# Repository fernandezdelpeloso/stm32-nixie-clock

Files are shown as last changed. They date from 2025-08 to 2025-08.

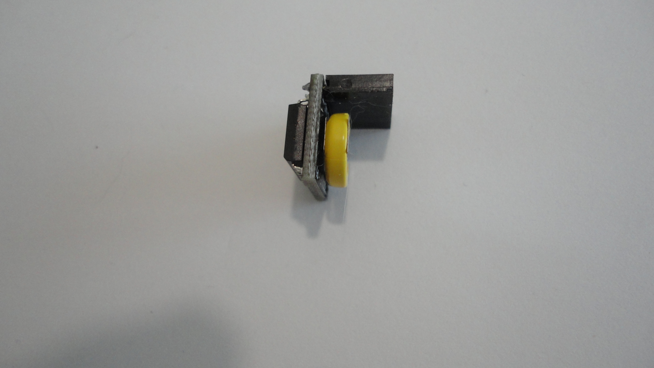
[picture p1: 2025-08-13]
media/images/DSC00116.JPG

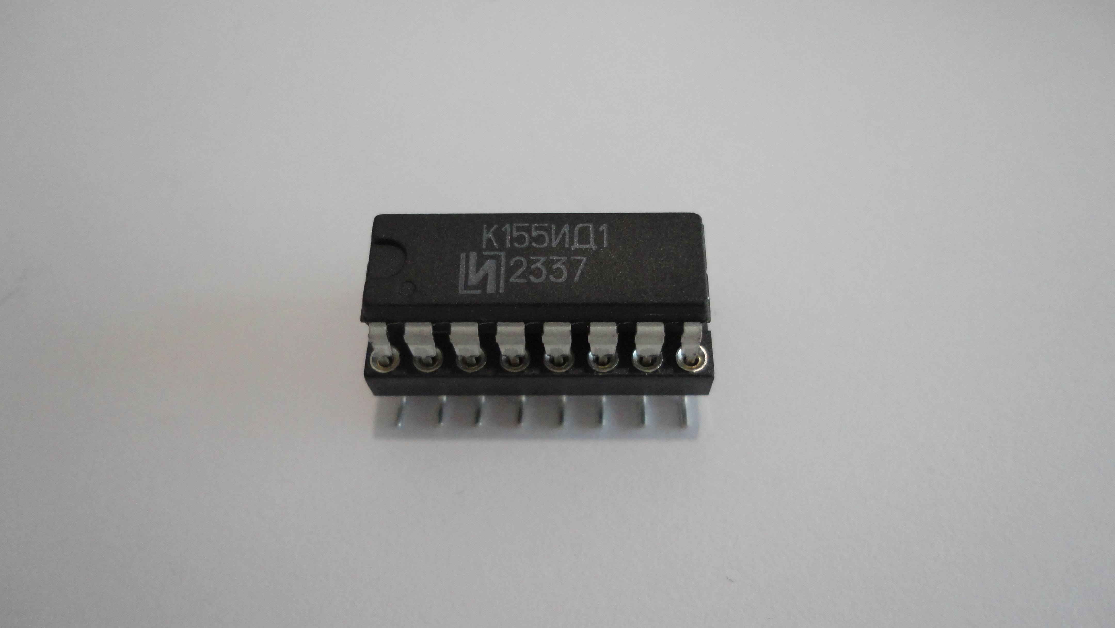
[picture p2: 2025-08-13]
media/images/DSC00112.JPG

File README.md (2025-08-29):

# STM32 Nixie Clock (R|Z568M)

**TL;DR:** One-tube Nixie clock (Dalibor Farny R|Z568M) on an STM32 Cortex-M4F with GPS time sync, RTC backup, and anti–cathode-poisoning routine.

[▶ Short demo (MP4)](media/videos/bright.mp4)
Thumbnail

## Hardware
- MCU: STM32L4A6RGT7
- Level shifting: PCA9306 (custom module)
- HV driver: K155ID1 (5 V logic)
- Time: NEO-M8N (UTC) + DS3231 (backup)

### Files in this repo
- Schematics (PDF): `hardware/exports/schematic/`
- PCB (design): `hardware/exporta/pcb`
- 3D (PCB model): `hardware/exports/3d/`
- BOM (CSV + iBOM): `hardware/exports/bom/`
- Native KiCad project: `hardware/kicad/`

## Firmware
`firmware/` (STM32CubeIDE project). Roadmap: GPS/NMEA parse, RTC sync, presence sensor → anti-poisoning routine, optional FreeRTOS + SystemView.

## Safety
**High voltage present.** Observe clearance/creepage and safe handling.

## License
MIT

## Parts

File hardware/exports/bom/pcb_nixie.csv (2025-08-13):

Reference | Value | Datasheet | Footprint | Qty | DNP
D1 | US1M_R3G | https://www.diodes.com/assets/Datasheets/ds16008.pdf | Diode_SMD:D_SMA | 1
D2 | SMAJ170A | https://www.littelfuse.com/media?itemid=75e32973-b177-4ee3-a0ff-cedaf1abdb93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 | Diode_SMD:D_SMA | 1
J1 | MCU SWD | B4B-XH-AMLFSN | Connector_JST:JST_XH_B4B-XH-A_1x04_P2.50mm_Vertical | 1
J2 | Omron | B4B-XH-AMLFSN | Connector_JST:JST_XH_B4B-XH-A_1x04_P2.50mm_Vertical | 1
J3 | GPS M8N | B4B-XH-AMLFSN | Connector_JST:JST_XH_B4B-XH-A_1x04_P2.50mm_Vertical | 1
J4 | Power_supply |  | Connector_JST:JST_XH_B4B-XH-A_1x04_P2.50mm_Vertical | 1
J5 | Littelfuse 0218.020HXP | B2B-XH-ALFSN | Connector_JST:JST_XH_B2B-XH-A_1x02_P2.50mm_Vertical | 1
J6 | OLED | B4B-XH-AMLFSN | Connector_JST:JST_XH_B4B-XH-A_1x04_P2.50mm_Vertical | 1
NX1 | FRONT |  | Nixie:nixie_socket_manual | 1
R0 | 1k2 | ~ | Resistor_SMD:R_1206_3216Metric | 1
R1,R10 | 4k7 | ~ | Resistor_SMD:R_1206_3216Metric,Resistor_SMD:R_2512_6332Metric | 2
R2,R5,R6 | 1k1 | ~ | Resistor_SMD:R_1206_3216Metric | 3
R3 | 1k5 | ~ | Resistor_SMD:R_1206_3216Metric | 1
R4 | 3k3 | ~ | Resistor_SMD:R_1206_3216Metric | 1
R7 | 3k6 | ~ | Resistor_SMD:R_1206_3216Metric | 1
R8 | 0R | ~ | Resistor_SMD:R_1206_3216Metric | 1
R9 | 1k | ~ | Resistor_SMD:R_1206_3216Metric | 1
RC0,RC1,RD0,RD1 | 10k | ~ | Resistor_SMD:R_0603_1608Metric | 4
REN1 | 200k | ~ | Resistor_SMD:R_0603_1608Metric | 1
U1 | STM32L4A6RGTx | https://www.st.com/resource/en/datasheet/stm32l4a6rg.pdf | Package_QFP:LQFP-64_10x10mm_P0.5mm | 1
U1C1 | 4.7U | ~ | Capacitor_SMD:C_0603_1608Metric | 1
U1C2,U1C3,U1C4,U1C5,U2C1,U2C2 | 100N | ~ | Capacitor_SMD:C_0603_1608Metric,Capacitor_SMD:C_0805_2012Metric | 6
U1C6 | 10N | ~ | Capacitor_SMD:C_0603_1608Metric | 1
U1C7,U3C1 | 1U | ~ | Capacitor_SMD:C_0603_1608Metric,Capacitor_SMD:C_0805_2012Metric | 2
U2 | TXB0104PW | http://www.ti.com/lit/ds/symlink/txb0104.pdf | Package_SO:TSSOP-14_4.4x5mm_P0.65mm | 1
U3 | K155id1 | datasheets/k155na1.pdf | Package_DIP:SMDIP-16_W7.62mm | 1
U4 | PCA9306D | https://www.nxp.com/docs/en/data-sheet/PCA9306.pdf | Package_SO:SO-8_3.9x4.9mm_P1.27mm | 1
U4C1 | 100P | ~ | Capacitor_SMD:C_0201_0603Metric | 1

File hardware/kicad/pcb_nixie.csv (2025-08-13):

Source: | /home/eduardo/Documents/070_NIXIE_CLOCK/pcb_nixie/pcb_nixie.kicad_sch
Date: | Do 29 Aug 2024 03:46:50 CEST
Tool: | Eeschema 6.0.2+dfsg-1
Generator: | /usr/share/kicad/plugins/bom_csv_grouped_by_value.py
Component Count: | 23
Individual Components:
Item | Qty | Reference(s) | Value | LibPart | Footprint | Datasheet | Spice_Model | Spice_Netlist_Enabled | Spice_Primitive
 |  | J1 | Conn_01x04_MountingPin | Connector_Generic_MountingPin:Conn_01x04_MountingPin | Connector_Molex:Molex_KK-254_AE-6410-04A_1x04_P2.54mm_Vertical | ~
 |  | NX1 | RTS-5 | NIXIEBIG:RTS-5 | Nixie:nixie_socket_manual
 |  | R0 | 1k2 | Device:R | Resistor_SMD:R_1206_3216Metric | ~
 |  | R1 | 4k7 | Device:R | Resistor_SMD:R_1206_3216Metric | ~
 |  | R2 | 1k1 | Device:R | Resistor_SMD:R_1206_3216Metric | ~
 |  | R3 | 1k5 | Device:R | Resistor_SMD:R_1206_3216Metric | ~
 |  | R4 | 3k3 | Device:R | Resistor_SMD:R_1206_3216Metric | ~
 |  | R5 | 1k1 | Device:R | Resistor_SMD:R_1206_3216Metric | ~
 |  | R6 | 1k1 | Device:R | Resistor_SMD:R_1206_3216Metric | ~
 |  | R7 | 3k6 | Device:R | Resistor_SMD:R_1206_3216Metric | ~
 |  | R8 | 0R | Device:R | Resistor_SMD:R_1206_3216Metric | ~
 |  | R9 | 1k | Device:R | Resistor_SMD:R_1206_3216Metric | ~ | 1k | Y | R
 |  | R11 | 4k7 | Device:R | Resistor_SMD:R_2512_6332Metric | ~
 |  | U1 | STM32F103RCT6 | MCU_ST_STM32F1:STM32F103RCTx | Package_QFP:LQFP-64_10x10mm_P0.5mm | http://www.st.com/st-web-ui/static/active/en/resource/technical/document/datasheet/CD00191185.pdf
 |  | U1C1 | 1U | Device:C | Capacitor_SMD:C_0805_2012Metric | ~
 |  | U1C2 | 1U | Device:C | Capacitor_SMD:C_0805_2012Metric | ~
 |  | U2 | TXB0104D | Logic_LevelTranslator:TXB0104D | Package_SO:SOIC-14_3.9x8.7mm_P1.27mm | http://www.ti.com/lit/ds/symlink/txb0104.pdf
 |  | U2C1 | 1U | Device:C | Capacitor_SMD:C_0805_2012Metric | ~
 |  | U2C2 | 1U | Device:C | Capacitor_SMD:C_0805_2012Metric | ~
 |  | U2C3 | 1U | Device:C | Capacitor_SMD:C_0805_2012Metric | ~
 |  | U3 | 155ИД1 | misc_giogziro95:155ИД1 | Package_DIP:SMDIP-16_W7.62mm | https://neon1.net/nixieclock/sn74141.pdf
 |  | U3C1 | 1U | Device:C | Capacitor_SMD:C_0805_2012Metric | ~
 |  | U3C2 | 1U | Device:C | Capacitor_SMD:C_0805_2012Metric | ~
Collated Components:
Item | Qty | Reference(s) | Value | LibPart | Footprint | Datasheet | Spice_Model | Spice_Netlist_Enabled | Spice_Primitive
1 | 1 | J1 | Conn_01x04_MountingPin | Connector_Generic_MountingPin:Conn_01x04_MountingPin | Connector_Molex:Molex_KK-254_AE-6410-04A_1x04_P2.54mm_Vertical | ~
2 | 1 | NX1 | RTS-5 | NIXIEBIG:RTS-5 | Nixie:nixie_socket_manual
3 | 1 | R0 | 1k2 | Device:R | Resistor_SMD:R_1206_3216Metric | ~
4 | 1 | R1 | 4k7 | Device:R | Resistor_SMD:R_1206_3216Metric | ~
5 | 3 | R2, R5, R6 | 1k1 | Device:R | Resistor_SMD:R_1206_3216Metric | ~
6 | 1 | R3 | 1k5 | Device:R | Resistor_SMD:R_1206_3216Metric | ~
7 | 1 | R4 | 3k3 | Device:R | Resistor_SMD:R_1206_3216Metric | ~
8 | 1 | R7 | 3k6 | Device:R | Resistor_SMD:R_1206_3216Metric | ~
9 | 1 | R8 | 0R | Device:R | Resistor_SMD:R_1206_3216Metric | ~
10 | 1 | R9 | 1k | Device:R | Resistor_SMD:R_1206_3216Metric | ~ | 1k | Y | R
11 | 1 | R11 | 4k7 | Device:R | Resistor_SMD:R_2512_6332Metric | ~
12 | 1 | U1 | STM32F103RCT6 | MCU_ST_STM32F1:STM32F103RCTx | Package_QFP:LQFP-64_10x10mm_P0.5mm | http://www.st.com/st-web-ui/static/active/en/resource/technical/document/datasheet/CD00191185.pdf
13 | 7 | U1C1, U1C2, U2C1, U2C2, U2C3, U3C1, U3C2 | 1U | Device:C | Capacitor_SMD:C_0805_2012Metric | ~
14 | 1 | U2 | TXB0104D | Logic_LevelTranslator:TXB0104D | Package_SO:SOIC-14_3.9x8.7mm_P1.27mm | http://www.ti.com/lit/ds/symlink/txb0104.pdf
15 | 1 | U3 | 155ИД1 | misc_giogziro95:155ИД1 | Package_DIP:SMDIP-16_W7.62mm | https://neon1.net/nixieclock/sn74141.pdf

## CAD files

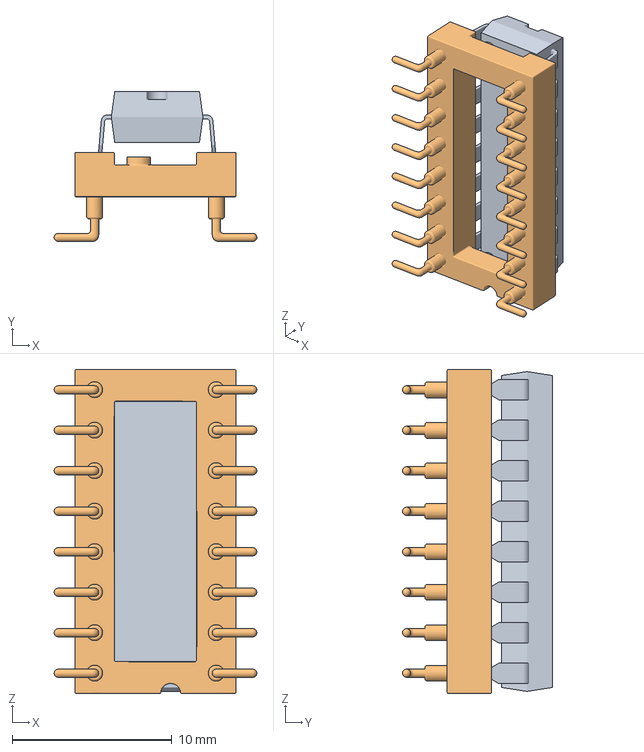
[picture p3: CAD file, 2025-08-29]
hardware/kicad/DIP16_TO_SMD.FCStd
12.7 x 9.40 x 20.3 mm
Scale001
dip_to_smd_socket110-xx-316-41-105000

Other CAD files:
hardware/kicad/1N5819HW_7_F/DIP-16 N.step
hardware/kicad/3d_models/B3B-XH-A.step
hardware/kicad/footprints/kicad-footprints-5.1.10/Sources/Inductor_SMD/L_Wuerth_WE-TPC-3816.FCStd
hardware/kicad/footprints/kicad-footprints-5.1.10/Sources/Package_LGA/Infineon_PG-LLGA-5-1.FCStd
hardware/kicad/footprints/kicad-footprints-5.1.10/Sources/Package_SON/X2SON-4_1x1mm_P0.65mm.fcstd
hardware/kicad/footprints/kicad-footprints-5.1.10/Sources/Package_TO_SOT_THT/sod-70.fcstd
hardware/kicad/16 DIP IC.stp
hardware/kicad/1N5819HW_7_F/1N5819HW-7-F.step
hardware/kicad/3d_models/B2B-XH-A.step
hardware/kicad/footprints/kicad-footprints-5.1.10/Sources/Inductor_SMD/L_Coilcraft_LPS5030.FCStd
hardware/kicad/footprints/kicad-footprints-5.1.10/Sources/Package_TO_SOT_THT/sod-70_P5.08mm.fcstd
hardware/kicad/DIP16withSOCKET.stl
hardware/kicad/DIP-16 N.step
hardware/kicad/Unnamed-Fusion.step
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

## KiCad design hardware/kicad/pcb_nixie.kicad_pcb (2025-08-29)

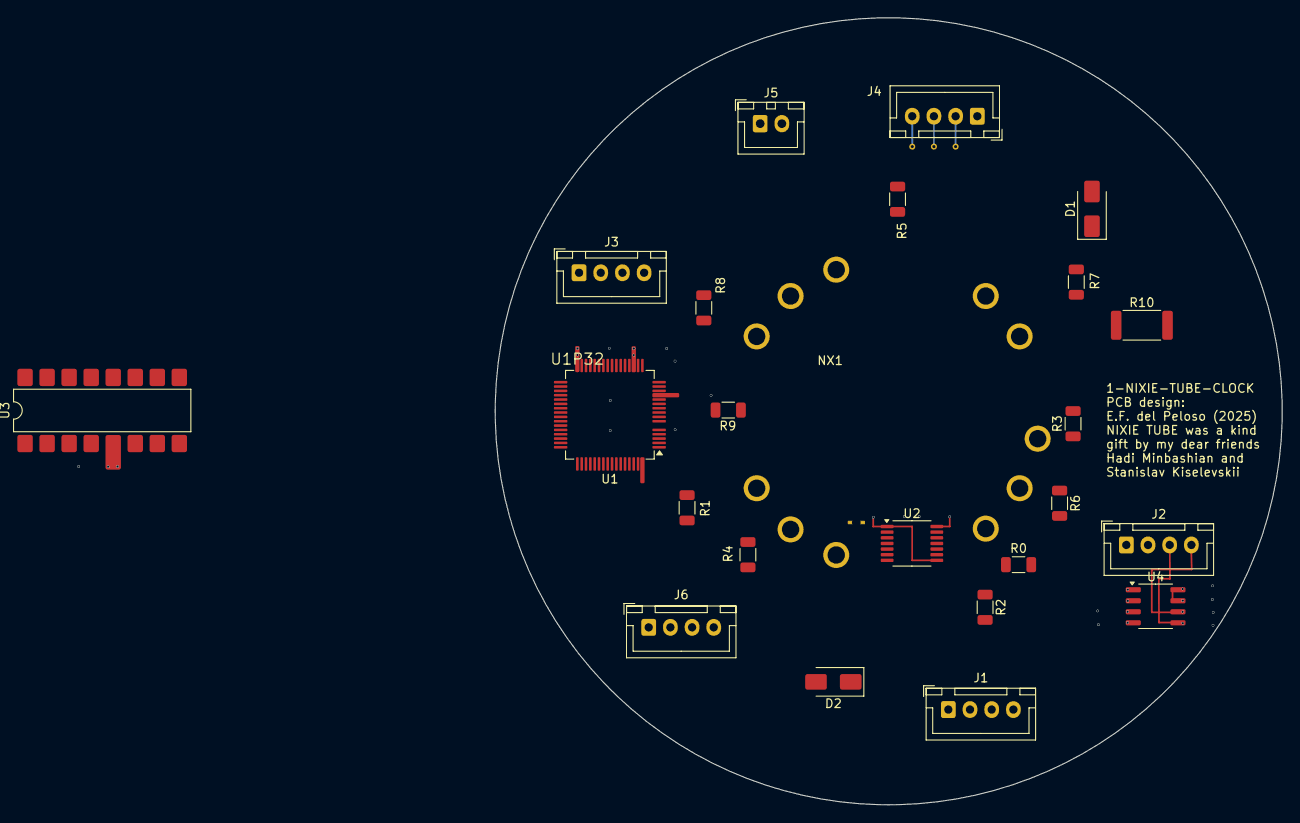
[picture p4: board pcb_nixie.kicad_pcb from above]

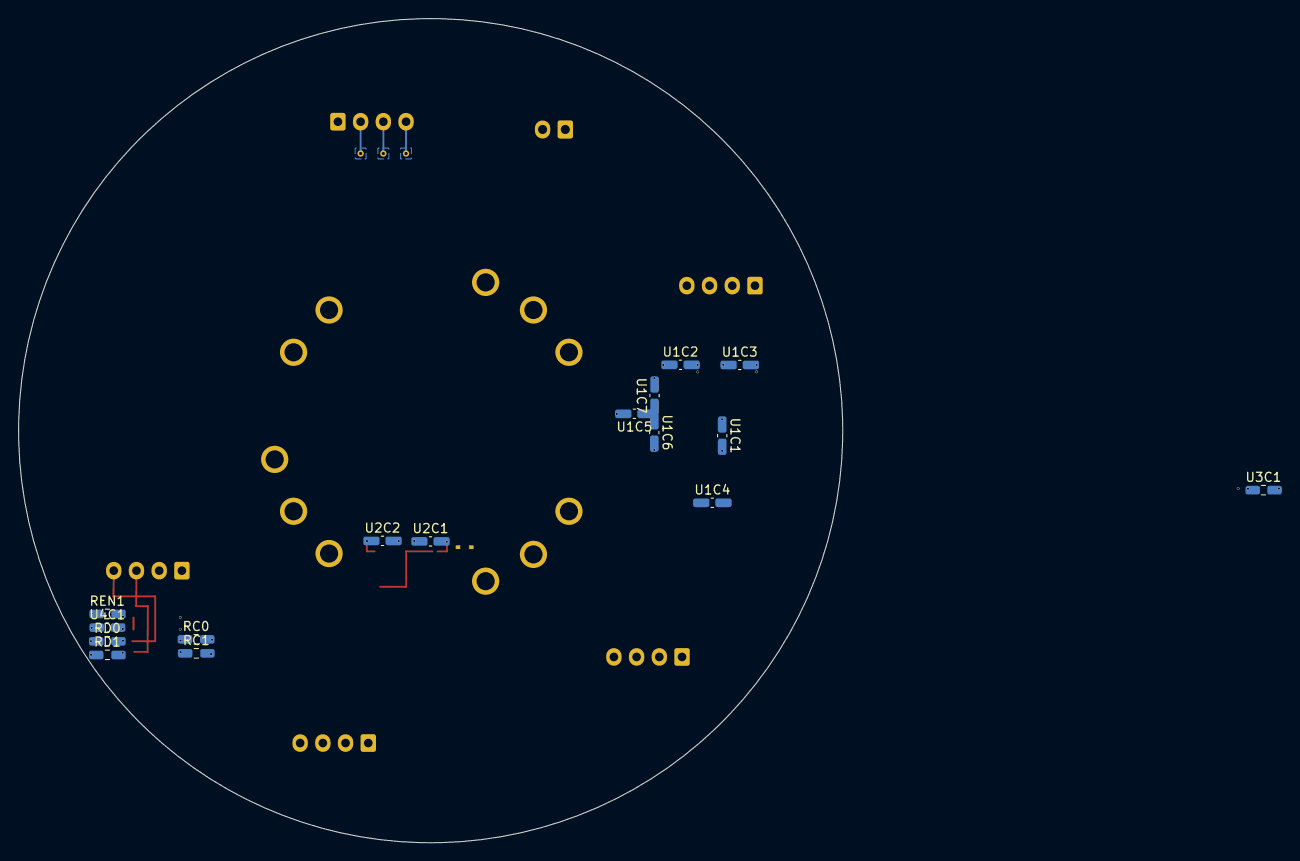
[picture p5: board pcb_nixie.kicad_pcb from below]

Board: 6 copper layers, 90.7 x 90.7 mm, 44 parts (16 on the bottom side), 45 nets, no tracks yet.

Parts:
D1: US1M_R3G; D_SMA
D2: SMAJ170A; D_SMA
J1: MCU-SWD; JST_XH_B4B-XH-A_1x04_P2.50mm_Vertical
J2: Omron; JST_XH_B4B-XH-A_1x04_P2.50mm_Vertical
J3: GPS-M8N; JST_XH_B4B-XH-A_1x04_P2.50mm_Vertical
J4: Power-supply; JST_XH_B4B-XH-A_1x04_P2.50mm_Vertical
J4P2, J4P3, J4P4: (no value)
J5: Littelfuse-0218.020HXP; JST_XH_B2B-XH-A_1x02_P2.50mm_Vertical
J6: OLED; JST_XH_B4B-XH-A_1x04_P2.50mm_Vertical
NX1: FRONT; nixie_socket_manual
R0: 1k2; R_1206_3216Metric
R1: 4k7; R_1206_3216Metric
R2, R5, R6: 1k1; R_1206_3216Metric
R3: 1k5; R_1206_3216Metric
R4: 3k3; R_1206_3216Metric
R7: 3k6; R_1206_3216Metric
R8: 0R; R_1206_3216Metric
R9: 1k; R_1206_3216Metric
R10: 4k7; R_2512_6332Metric
RC0, RC1: 10k; R_0603_1608Metric
RD0, RD1: 10k; R_0603_1608Metric
REN1: 200k; R_0603_1608Metric
U1: STM32L4A6RGTx; LQFP-64_10x10mm_P0.5mm
U1C1: 4.7U; C_0603_1608Metric
U1C2, U1C3, U1C4, U1C5, U1C6, U1C7, U2C1, U2C2: 100N; C_0603_1608Metric
U1P32: (no value)
U2: TXB0104PW; TSSOP-14_4.4x5mm_P0.65mm
U3: K155id1; SMDIP-16_W7.62mm
U3C1: 1U; R_0603_1608Metric
U4: PCA9306D; SO-8_3.9x4.9mm_P1.27mm
U4C1: 100P; C_0603_1608Metric

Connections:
+3V3: J3.4 (+3V3), J4.4 (3V3), J4P4.17, J6.3 (3V3), RC0.2, RC1.1, U1.1 (VBAT), U1.13 (VDDA), U1.19 (VDD), U1.32 (VDD), U1.48 (VDDUSB), U1C1.2, U1C2.2, U1P32.32 (VDD), U2.1 (VCCA), U2.8 (OE), U4.2 (VREF1)
+5V: J2.2 (+5V), J4.3 (5V), J4P3.16, RD0.2, RD1.1, REN1.1, REN1.2, U2.14 (VCCB), U4.7 (VREF2), U4.8 (EN)
/A1: U1.14 (PA0), U2.2 (A1)
/A2: U1.15 (PA1), U2.3 (A2)
/A3: U1.20 (PA4), U2.4 (A3)
/A4: U1.21 (PA5), U2.5 (A4)
/B1: U2.13 (B1), U3.3 (A)
/B2: U2.12 (B2), U3.6 (B)
/B3: U2.11 (B3), U3.7 (C)
/B4: U2.10 (B4), U3.4 (D)
/PCA9306/SCL: RC0.1, U1.61 (PB8), U4.3 (SCL1)
/PCA9306/SDA: U1.62 (PB9), U4.4 (SDA1)
/RA0: R0.1, U3.16 (0)
/RA1: R1.2, U3.15 (1)
/RA2: R2.1, U3.8 (2)
/RA3: R3.1, U3.9 (3)
/RA4: R4.1, U3.13 (4)
/RA5: R5.1, U3.14 (5)
/RA6: R6.2, U3.11 (6)
/RA7: R7.1, U3.10 (7)
/RA8: R8.2, U3.1 (8)
/RA9: R9.1, U3.2 (9)
/RB0: NX1.0, R0.2
/RB1: NX1.1, R1.1
/RB2: NX1.2, R2.2
/RB3: NX1.3, R3.2
/RB4: NX1.4, R4.2
/RB5: NX1.5, R5.2
/RB6: NX1.6, R6.1
/RB7: NX1.7, R7.2
/RB8: NX1.8, R8.1
/RB9: NX1.9, R9.2
GND: D1.2 (A), D2.2 (A2), J1.3 (GND), J2.1 (GND), J3.1 (GND), J4.2 (GND), J4P2.15, J6.4 (GND), U1.12 (VSSA), U1.18 (VSS), U1.31 (VSS), U1.47 (VSS), U1.63 (VSS), U1C1.1, U1C3.2, U1C4.1, U2.7 (GND), U3.12 (GND), U4C1.1, U4C1.2
HT: D2.1 (A1), J4.1 (170V), J5.1
unnamed: D1.1 (K), NX1.10, R10.2
unnamed: J1.4 (RST), U1.7 (NRST)
unnamed: J1.1 (SWCLK), U1.49 (PA14)
unnamed: J1.2 (SWDIO), U1.46 (PA13)
unnamed: J2.4 (SCL), RD0.1, U4.6 (SCL2)
unnamed: J2.3 (SDA), RD1.2, U4.5 (SDA2)
unnamed: J3.2 (Rx), U1.30 (PB11)
unnamed: J3.3 (Tx), U1.24 (PC4)
unnamed: J5.2, R10.1
unnamed: J6.1 (SCL), U1.58 (PB6)
unnamed: J6.2 (SDA), U1.59 (PB7)

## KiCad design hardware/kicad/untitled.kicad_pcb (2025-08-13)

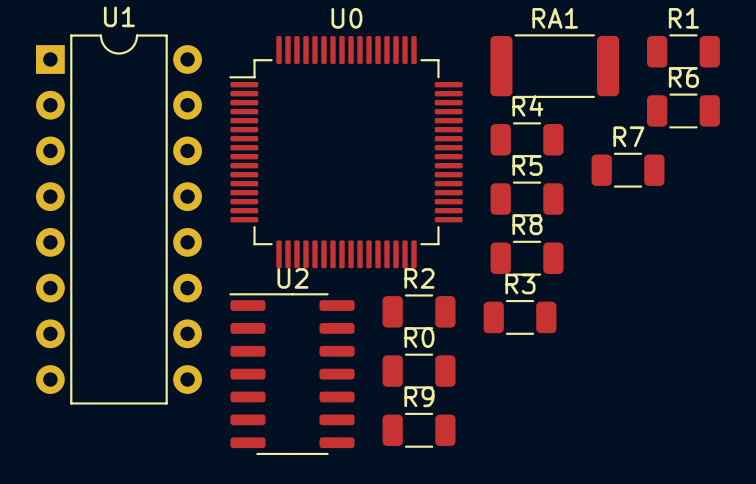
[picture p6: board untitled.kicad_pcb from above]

Board: 2 copper layers, 14 parts (0 on the bottom side), 19 nets, no tracks yet.

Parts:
R0: 1k2; R_1206_3216Metric
R1: 4k7; R_1206_3216Metric
R2, R5, R6: 1k1; R_1206_3216Metric
R3: 1k5; R_1206_3216Metric
R4: 3k3; R_1206_3216Metric
R7: 3k6; R_1206_3216Metric
R8: 0R; R_1206_3216Metric
R9: 1k; R_1206_3216Metric
RA1: 4k7; R_2512_6332Metric
U0: STM32F103RCT6; LQFP-64_10x10mm_P0.5mm
U1: 155ИД1; DIP-16_W7.62mm
U2: TXB0104D; SOIC-14_3.9x8.7mm_P1.27mm

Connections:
+5V: U1.5 (VCC), U2.14 (VCCB)
unnamed: R0.1, U1.16 (0)
unnamed: R1.2, U1.15 (1)
unnamed: R2.1, U1.8 (2)
unnamed: R3.1, U1.9 (3)
unnamed: R4.1, U1.13 (4)
unnamed: R5.1, U1.14 (5)
unnamed: R6.2, U1.11 (6)
unnamed: R7.1, U1.10 (7)
unnamed: R8.2, U1.1 (8)
unnamed: R9.1, U1.2 (9)
unnamed: U0.14 (PA0), U2.2 (A1)
unnamed: U0.15 (PA1), U2.3 (A2)
unnamed: U0.16 (PA2), U2.4 (A3)
unnamed: U0.17 (PA3), U2.5 (A4)
unnamed: U1.3 (A), U2.13 (B1)
unnamed: U1.4 (D), U2.10 (B4)
unnamed: U1.6 (B), U2.12 (B2)
unnamed: U1.7 (C), U2.11 (B3)

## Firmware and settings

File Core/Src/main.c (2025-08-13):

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
/* Includes ------------------------------------------------------------------*/
#include "main.h"

/* USER CODE BEGIN Includes */
#include <string.h>
#include <stdlib.h>
#include <stdbool.h>
#include "math.h"
#include <stdio.h>
#include "lookup_table.h"
#include "ds3231_for_stm32_hal.h"
#include "ssd1306_fonts.h"

/* USER CODE END Includes */

/* USER CODE BEGIN PD */

/* Setup for OLED */
#define SSD1306_INCLUDE_FONT_7x10
#define SSD1306_INCLUDE_FONT_16x26
#define D6T_ADDR 0x0A  // for I2C 7bit address
#define D6T_CMD 0x4C  // for D6T-44L-06/06H, D6T-8L-09/09H, for D6T-1A-01/02
#define N_ROW 1
#define N_PIXEL 1
#define N_READ ((N_PIXEL + 1) * 2 + 1)

/* Setup for IR presence detector
#define D6T_I2C_ADDR     (0x0A << 1)   // HAL expects 8-bit address
#define D6T_READ_LEN     5
#define D6T_CMD          0x4C

/* USER CODE END PD */

I2C_HandleTypeDef hi2c1;
I2C_HandleTypeDef hi2c3;
I2C_HandleTypeDef hi2c4;

UART_HandleTypeDef huart2;
UART_HandleTypeDef huart3;

/* USER CODE BEGIN PV */

/* Buffer to read */
char rx_data[2048];

/* USER CODE END PV */

void SystemClock_Config(void);
static void MX_GPIO_Init(void);
static void MX_USART2_UART_Init(void);
static void MX_I2C1_Init(void);
static void MX_I2C3_Init(void);
static void MX_I2C4_Init(void);
static void MX_USART3_UART_Init(void);
/* USER CODE BEGIN 0 */

const size_t lookup_table_length = sizeof(lookup_table) / sizeof(lookup_table[0]);

#define DEG_TO_RAD(deg) ((deg) * M_PI / 180.0)
#define EARTH_RADIUS_KM 6371.0

float haversine(float lat1, float lon1, float lat2, float lon2) {
    float dlat = DEG_TO_RAD(lat2 - lat1);
    float dlon = DEG_TO_RAD(lon2 - lon1);
    float a = sinf(dlat / 2) * sinf(dlat / 2) +
              cosf(DEG_TO_RAD(lat1)) * cosf(DEG_TO_RAD(lat2)) *
              sinf(dlon / 2) * sinf(dlon / 2);
    float c = 2 * atan2f(sqrtf(a), sqrtf(1 - a));
    return EARTH_RADIUS_KM * c;
}

const CsvRow* find_closest_entry(float my_lat, float my_lon) {
    const CsvRow* best = NULL;
    float min_distance = 1e9f;  // big initial value

    for (size_t i = 0; i < lookup_table_length; i++) {
        float d = haversine(my_lat, my_lon, lookup_table[i].Latitude, lookup_table[i].Longitude);
        if (d < min_distance) {
            min_distance = d;
            best = &lookup_table[i];
        }
    }

    return best;
}


int16_t conv8us_s16_le(uint8_t* buf, int n) {
    uint16_t ret;
    ret = (uint16_t)buf[n];
    ret += ((uint16_t)buf[n + 1]) << 8;
    return (int16_t)ret;   // and convert negative.
}

int day_of_year(int year, int month, int day) {
    static const int days_before_month[] = {
        0, 31, 59, 90, 120, 151, 181,
        212, 243, 273, 304, 334
    };
    int doy = days_before_month[month - 1] + day;

    // Leap year correction
    if (month > 2 &&
        ((year % 4 == 0 && year % 100 != 0) || year % 400 == 0)) {
        doy += 1;
    }

    return doy;
}

static bool already_read_gps = false;


uint8_t pin_values[4];
uint8_t pin_numbers[4] = {0, 1, 4, 5};
 int time_h_m[4];
 int count_numbers, count_bits;
 int delay_time;
//#define GPIO_PINS (GPIO_PIN_0 | GPIO_PIN_1 | GPIO_PIN_2 | GPIO_PIN_7)

/* USER CODE END 0 */

/**
  * @brief  The application entry point.
  * @retval int
  */
int main(void)
{

  /* USER CODE BEGIN 1 */
    uint8_t d6t_addr = 0x0A << 1;  // 7-bit address shifted for STM32 HAL
    uint8_t cmd = 0x4C;
    uint8_t rx_buf[5];  // 1 status + 2 bytes for 1 temperature + 2 CRC
  /* USER CODE END 1 */

  /* MCU Configuration--------------------------------------------------------*/

  /* Reset of all peripherals, Initializes the Flash interface and the Systick. */
  HAL_Init();

  /* Configure the system clock */
  SystemClock_Config();

  /* Initialize all configured peripherals
  	 usart2 	  -
  	 usart3 	  -
  	 I2C1 (hi2c1) -
  	 I2C3 (hi2c3) -
  	 I2C4 (hi2c4) -
  */

  MX_GPIO_Init();
  MX_USART2_UART_Init();
  MX_I2C1_Init();
  MX_I2C3_Init();
  MX_I2C4_Init();
  MX_USART3_UART_Init();
  /* USER CODE BEGIN 2 */
  int time_h_m[4];
  ssd1306_Init();
  DS3231_Init(&hi2c3);
  /* USER CODE END 2 */

  /* Infinite loop */
  /* USER CODE BEGIN WHILE */
  while (1)
  {
    /* USER CODE END WHILE */

    /* USER CODE BEGIN 3 */

		void control_pins(uint8_t pin_values[4], uint8_t pin_numbers[4])
		{
			  //HAL_GPIO_WritePin(GPIOA, GPIO_PIN_0|GPIO_PIN_1|GPIO_PIN_2|GPIO_PIN_7, GPIO_PIN_RESET);


		    // Iterate through the pin values vector
		    for (int i = 0; i < 4; i++) {
		        if (pin_values[i] > 0) {
		            // Set pin high (raise)
		            HAL_GPIO_WritePin(GPIOA, (int)(pow(2, pin_numbers[i])), GPIO_PIN_SET);  // Map index to GPIO pin
		        } else {
		            // Set pin low (lower)
		            HAL_GPIO_WritePin(GPIOA, (int)(pow(2, pin_numbers[i])), GPIO_PIN_RESET);  // Map index to GPIO pin
		        }
		    }
		}

	  HAL_UART_Receive_IT(&huart3, rx_data, sizeof(rx_data));


	  if (HAL_I2C_Master_Transmit(&hi2c1, d6t_addr, &cmd, 1, HAL_MAX_DELAY) != HAL_OK)
	      {
	          printf("Transmit failed!\r\n");
	          HAL_Delay(1000);
	          continue;
	      } else {
	    	  printf("Transmit OK!!!!\r\n");
	      }

	    uint8_t rawData[5] = {0};
	    uint8_t command = D6T_CMD;

	    HAL_Delay(500);

	    if (HAL_I2C_Master_Receive(&hi2c1, d6t_addr, rawData, 5, HAL_MAX_DELAY) != HAL_OK) {
	        printf("I2C READ FAILED\r\n");
	    }

	    int16_t temp_pixel = (int16_t)(rawData[3] << 8 | rawData[2]);
	    float temperature = temp_pixel / 10.0f;

	    printf("Raw Pixel Temp: %d (%d C)\r\n", (int)temp_pixel, (int)temperature);

	    HAL_Delay(500);

	  uint8_t hour = DS3231_GetHour();
	  uint8_t minute = DS3231_GetMinute();


	  time_h_m[1] = hour % 10;
	  time_h_m[0] = (int)(hour / 10);

	  time_h_m[3] = minute % 10;
	  time_h_m[2] = (int)(minute / 10);

	  for (count_numbers = 0; count_numbers < 4; count_numbers++) {

		  HAL_GPIO_WritePin(GPIOA, GPIO_PIN_0|GPIO_PIN_1|GPIO_PIN_2|GPIO_PIN_6|GPIO_PIN_3|GPIO_PIN_4|GPIO_PIN_5|GPIO_PIN_7, GPIO_PIN_SET);

		  switch (count_numbers)  {
					case 0:
						delay_time = 1500;
						break;
					case 1:
					case 3:
						delay_time = 125;
						break;
					case 2:
						delay_time = 500;
		  }

		  HAL_Delay(delay_time);


		  for (count_bits = 0; count_bits < 4; count_bits++) {
			  pin_values[count_bits] = time_h_m[count_numbers] & (int)pow(2, count_bits);
		  }

		  control_pins(pin_values, pin_numbers);

		  HAL_Delay(500);

	  }

	  char time_str[24];
	  snprintf(time_str, sizeof(time_str), "%02d:%02d UTC - %d oC", hour, minute, (int)temperature);
	  printf("\r\n\n");
	  printf(time_str);
	  printf("\r\n\n");


	  ssd1306_Fill(Black);
	  ssd1306_SetCursor(0, 0);
	  ssd1306_WriteString(time_str, Font_7x10, White);
	  // ssd1306_Fill(1);
	  ssd1306_UpdateScreen();

  }
  /* USER CODE END 3 */
}

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
/* USER CODE BEGIN 4 */
int _write(int file, char *ptr, int len)
{
    HAL_UART_Transmit(&huart2, (uint8_t*)ptr, len, HAL_MAX_DELAY);
    return len;
}

bool validate_nmea_checksum(const char* sentence) {
    if (sentence[0] != '$') return false;

    const char* checksum_str = strstr(sentence, "*");
    int sizestr = strlen(checksum_str);
    if (!checksum_str || strlen(checksum_str) < 3) return false;

    uint8_t checksum = 0;
    for (const char* p = sentence; *p != '*' && *p != '\0'; p++) {
        checksum ^= *p;
    }

    uint8_t received;
    sscanf(checksum_str + 1, "%2hhX", &received);
    return checksum == received;
}

void HAL_UART_RxCpltCallback(UART_HandleTypeDef *huart)
{
	/* Prevent unused argument(s) compilation warning */
	UNUSED(huart);

	if (!already_read_gps)
	{


		  // String to be analysed starts with $
		  char* substr = strstr(rx_data, "$GNRMC");
		  if (substr == NULL) return;

		  // and ends after the checksum
		  char* substr2 = strstr(substr, "\*");
		  if (substr2 == NULL || substr2[1] == '\0' || substr2[2] == '\0') return;
		  substr2[3] = '\0';

		  if (!validate_nmea_checksum(substr)) return;


		  // Parse GPS message
		  char** parsed_gps = parse_csv(substr);

		  // Returns if GPS data in invalid
		  if (parsed_gps[2][0] == 'V') return;

		  ssd1306_SetCursor(0,18);
		  ssd1306_WriteString("Valid GPS message!", Font_7x10, White);
		  ssd1306_UpdateScreen();

		  // Longitude extraction
		  double lon= atof(parsed_gps[5]);
		  int londeg = (int)(lon / 100);
		  double lonmin = lon - londeg * 100;
		  lon = londeg + lonmin / 60.0;
		  if (parsed_gps[6][0] == 'W') lon = -lon;
		  else if (parsed_gps[6][0] != 'E') return;

		  // Latitude extraction
		  double lat = atof(parsed_gps[3]);
		  int latdeg =  (int)(lat / 100);
		  double latmin = lat - latdeg * 100;
		  lat = latdeg + latmin / 60.0;
		  if (parsed_gps[4][0] == 'S') lat = -lat;
		  else if (parsed_gps[4][0] != 'N') return;

		  const CsvRow* nearest = find_closest_entry(lat, lon);

		  // Get UTC time from GPS (parsed_gps[1] format is "hhmmss.sss")
		  char* utc_str = parsed_gps[1];
		  int gps_hour = (utc_str[0] - '0') * 10 + (utc_str[1] - '0');
		  int gps_min = (utc_str[2] - '0') * 10 + (utc_str[3] - '0');
		  int gps_sec = (utc_str[4] - '0') * 10 + (utc_str[5] - '0');

		  // Get date from GPS (parsed_gps[9] format is "ddmmyy")
		  char* date_str = parsed_gps[9];
		  int gps_day = (date_str[0] - '0') * 10 + (date_str[1] - '0');
		  int gps_month = (date_str[2] - '0') * 10 + (date_str[3] - '0');
		  int gps_year = 2000 + (date_str[4] - '0') * 10 + (date_str[5] - '0');

		  // Build date string for DST comparison
		  char today[11];
		  snprintf(today, sizeof(today), "%04d-%02d-%02d", gps_year, gps_month, gps_day);

		  bool DST = false;

		  // Determine if DST applies
		  int doy = day_of_year(gps_year, gps_month, gps_day);
		  float local_offset = nearest->UTC_Offset;
		  if (nearest->DST_Start_DOY > 0 &&
			  doy >= nearest->DST_Start_DOY &&
			  doy <= nearest->DST_End_DOY) {
			  local_offset += 1.0f;
			  DST = true;
		  }

		  // Apply local offset
		  int corrected_hour = gps_hour + (int)local_offset;
		  if (corrected_hour >= 24) corrected_hour -= 24;
		  if (corrected_hour < 0) corrected_hour += 24;

		  char time_str[24];
		  char offset[4];
		  if (fabs(local_offset - (int)local_offset) > 0.00000001) snprintf(offset, sizeof(offset), "%.1f", local_offset);
		  else snprintf(offset, sizeof(offset), "%d", (int)local_offset);
		  snprintf(time_str, sizeof(time_str), "%02d:%02d UTC%s%s", corrected_hour, gps_min, (lon >= 0.0) ? "+" : "-", offset);
		  if (DST) snprintf(time_str, sizeof(time_str), "%s \(DST\)", time_str);
		  ssd1306_Fill(Black);
		  ssd1306_SetCursor(0, 0);
		  ssd1306_WriteString("Data from the GPS:", Font_7x10, White);
		  ssd1306_SetCursor(0, 11);
		  ssd1306_WriteString(time_str, Font_7x10, White);
		  ssd1306_SetCursor(0, 22);
		  ssd1306_WriteString("Saving to the RTC.", Font_7x10, White);
		  ssd1306_UpdateScreen();

		  //HAL_Delay(1);

		  // Update DS3231 with corrected time
		  DS3231_SetFullTime(corrected_hour, gps_min, gps_sec);
		  DS3231_SetFullDate(gps_day, gps_month, 1, gps_year); // 1 = Monday placeholder

		  ssd1306_Fill(Black);
		  ssd1306_SetCursor(25,4);
		  ssd1306_WriteString("Time saved.", Font_7x10, White);
		  ssd1306_SetCursor(25,18);
		  ssd1306_WriteString("RTC in use!", Font_7x10, White);
		  ssd1306_UpdateScreen();

		  //HAL_Delay(1000);
		  //int b = 1;
		  //for (int a = 0; a < 50000000; a++) b++;

		  //delay_us(10);

		  //ssd1306_Fill(Black);
		  //ssd1306_UpdateScreen();

		  already_read_gps = true;
	}

}
/* USER CODE END 4 */
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


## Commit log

2025-08-13 Initial commit: STM32 code, KiCad project, and documentation
    [1N5819HW-7-F.step, BOM_pcb_nixie.csv, SMDIP-14_W7.62mm.step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]
2025-08-13 Correcting problems with duplicate folders
    [1N5819HW-7-F.step, BOM_pcb_nixie.csv, SMDIP-14_W7.62mm.step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]
2025-08-29 keep on working the schematics and PCB
    [16 DIP IC.stp, B2B-XH-A.step, B3B-XH-A.step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]

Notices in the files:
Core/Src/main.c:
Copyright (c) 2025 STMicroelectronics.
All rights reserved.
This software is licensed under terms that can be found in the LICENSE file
